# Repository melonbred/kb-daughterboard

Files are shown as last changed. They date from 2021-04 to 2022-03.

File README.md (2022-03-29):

# kb-daughterboard

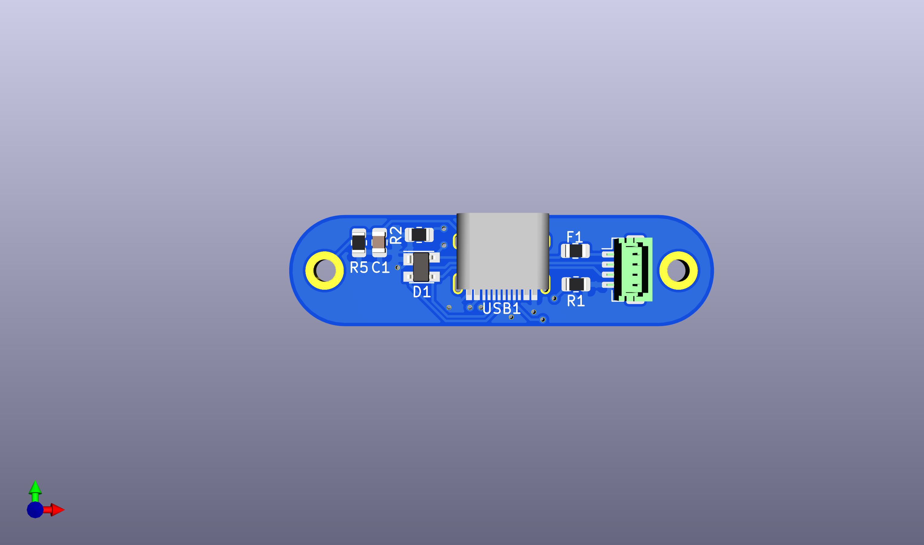
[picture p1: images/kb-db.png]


## Introduction

This project is a USB-C daughterboard that provides with ESD protection and a standard 4-pin JST connector. Dimensions are approximately 42 x 11mm and has two M2 screw mounts. This daughterboard was heavily influenced by the [C3 Unified Daughterboard](https://github.com/ai03-2725/Unified-Daughterboard) project. While the C3 Unified Daughterboard is a great product, this daughterboard offers a different footprint and vertical JST connector.

## Features
Similarly to the Unified Daugherboard, this daughterboard features the following:
- Overcurrent protection through a PTC fuse
- Overvoltage protection through a TVS diode
- Single-path USB-C shield grounding to a metal chasis. ESD is disappited through a resistor and diode.

Please note that this daughterboard does not include resistors for the USB data lines which may be required for some microprocessors. If these resistors are required for your application, please provide them on the PCB mainboard.

There are also two versions of this daughterboard. One with the USB-C receptacle flush to the PCB; The other with the USB-C receptacle protruded out. Please see the .step files for reference.

## Production
Please note that the produection files were prepared with JLCPCB's SMT assembly in mind. Should you deicide to proceed with a different manufacturer, the Bill of Materials (BOM) and position files may need to be modified.

## Acknowledgment

This project was collaboration with [matthewdias](https://github.com/matthewdias).

As mentioned above, this project was heavily influenced by the [C3 Unified Daughterboard](https://github.com/ai03-2725/Unified-Daughterboard).

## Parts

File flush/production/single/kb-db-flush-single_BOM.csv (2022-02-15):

Designator | Footprint | Quantity | Value | LCSC Part #
J1 | JST_SH_BM04B-SRSS-TB_1x04-1MP_P1.00mm_Vertical | 1 | Conn_01x04 | C160390
C1 | C_0805_2012Metric | 1 | 4.7n | C541501
USB1 | HRO-TYPE-C-31-M-12-Assembly | 1 | HRO-TYPE-C-31-M-12 | C167321
R5 | R_0805_2012Metric | 1 | 1M | C325768
R2,R1 | R_0805_2012Metric | 2 | 5.1k | C26023
F1 | Fuse_0805_2012Metric | 1 | 500mA | C883103
D1 | SOT-143 | 1 | PRTR5V0U2X | C2827688

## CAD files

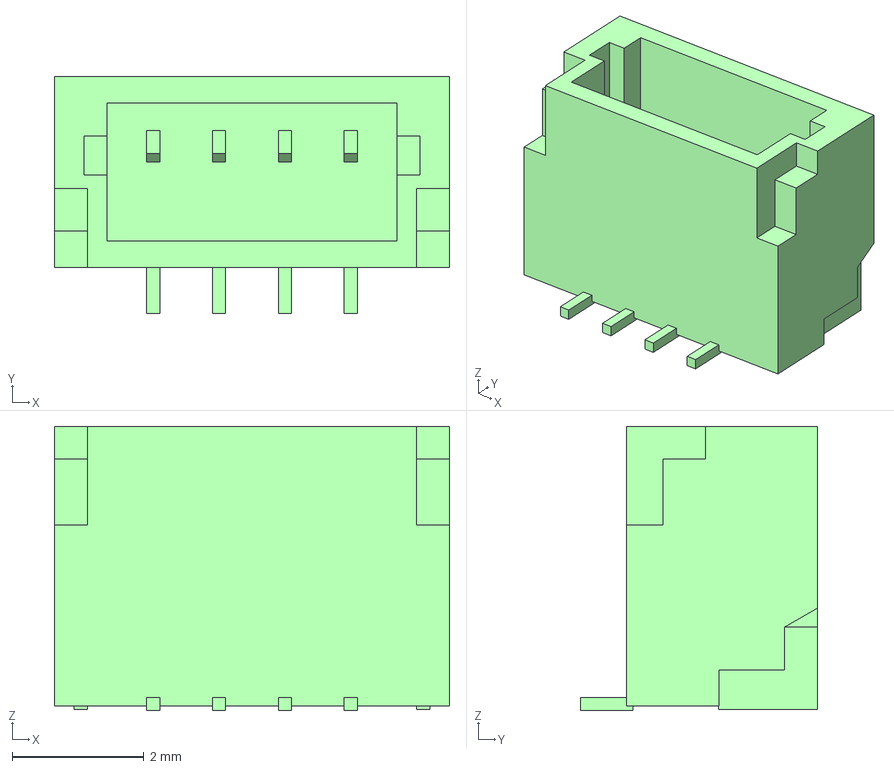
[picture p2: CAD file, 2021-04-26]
flush/kicad/jst/JST_-_BM04B-SRSS-TBLFSN.step
6.00 x 3.60 x 4.32 mm

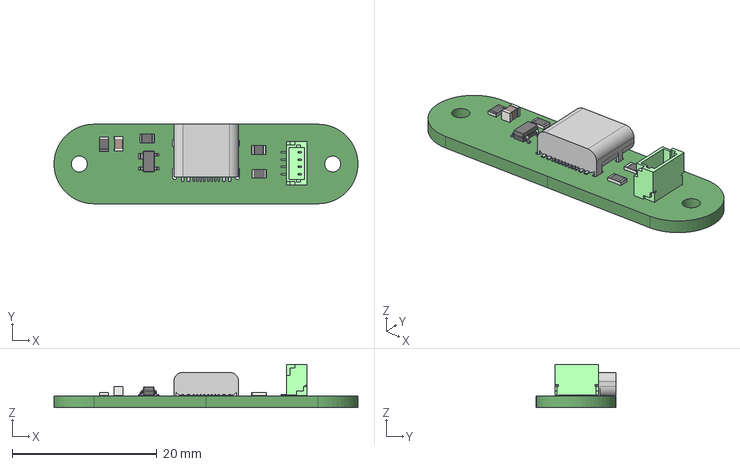
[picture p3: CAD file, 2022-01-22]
flush/kicad/step/kb-db.step
42.0 x 11.0 x 5.95 mm

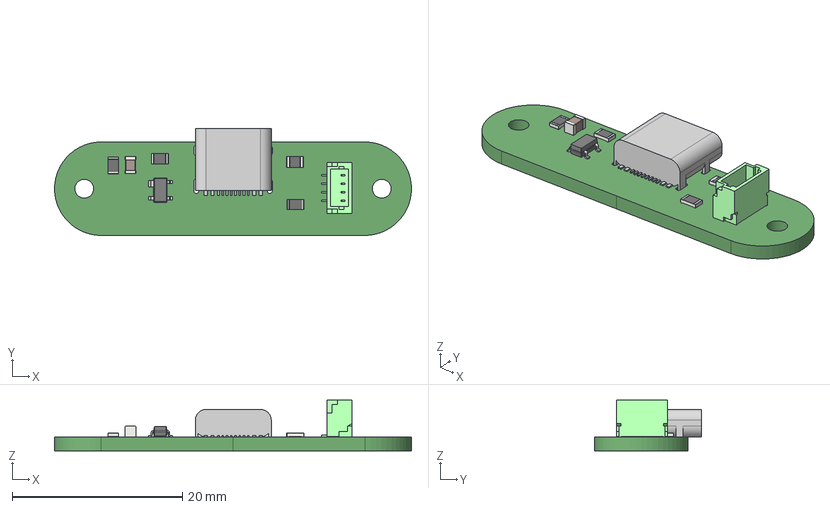
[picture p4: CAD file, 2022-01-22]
protruded/step/kb-db_protruded.step
42.0 x 12.6 x 5.95 mm

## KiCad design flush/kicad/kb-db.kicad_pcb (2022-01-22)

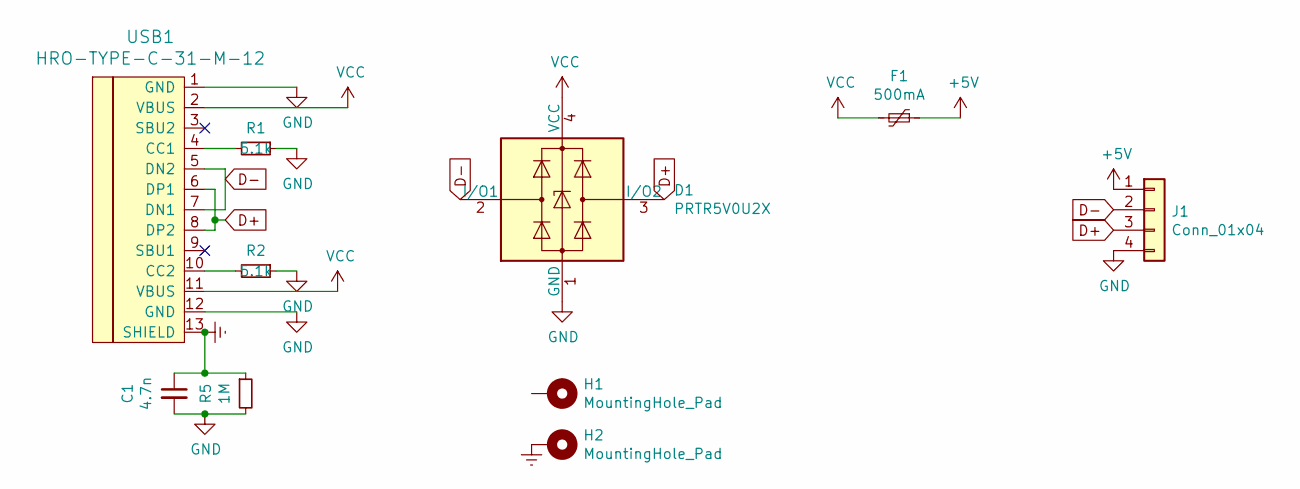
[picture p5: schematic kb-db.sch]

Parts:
C1: 4.7n; C_0805_2012Metric
D1: PRTR5V0U2X; SOT-143
F1: 500mA; Fuse_0805_2012Metric
H1, H2: MountingHole_Pad; MountingHole_2.2mm_M2_DIN965_Pad
J1: Conn_01x04; JST_SH_BM04B-SRSS-TB_1x04-1MP_P1.00mm_Vertical
R1, R2: 5.1k; R_0805_2012Metric
R5: 1M; R_0805_2012Metric
USB1: HRO-TYPE-C-31-M-12; HRO-TYPE-C-31-M-12-Assembly

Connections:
+5V: F1.1, J1.1
D+: D1.3 (I/O2), J1.3, USB1.6 (DP1), USB1.8 (DP2)
D-: D1.2 (I/O1), J1.2, USB1.5 (DN2), USB1.7 (DN1)
Earth: C1.1, H2.1, R5.1, USB1.13 (SHIELD)
GND: C1.2, D1.1 (GND), J1.4, R1.1, R2.1, R5.2, USB1.1 (GND), USB1.12 (GND)
unnamed: R1.2, USB1.4 (CC1)
unnamed: R2.2, USB1.10 (CC2)
VCC: D1.4 (VCC), F1.2, USB1.2 (VBUS), USB1.11 (VBUS)

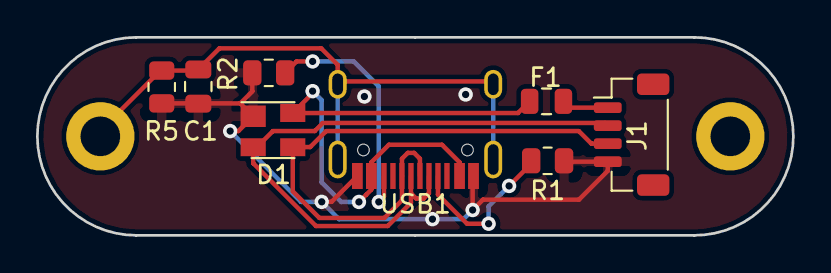
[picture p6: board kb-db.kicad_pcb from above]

Board: 2 copper layers, 42.0 x 11.0 mm, 10 parts (0 on the bottom side), 8 nets.

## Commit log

2021-04-26 Added pcb render
2021-04-26 Cleaned up unecessary footprints
2021-04-26 Added step
    [kb-db.step]
2021-05-03 Added production data
    [kb-db-B_Cu.gbr, kb-db-B_Mask.gbr, kb-db-B_Paste.gbr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]
2021-05-03 Updated cpl
    [kb-db_panel-top-pos.csv]
2022-01-15 Ground components to USB ground
    [kb-db-B_Cu.gbr, kb-db-B_Mask.gbr, kb-db-B_Paste.gbr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]
2022-01-22 added protruded version. file management
    [JST_-_BM04B-SRSS-TBLFSN.step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]
